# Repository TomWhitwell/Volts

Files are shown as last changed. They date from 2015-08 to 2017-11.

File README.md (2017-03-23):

##Turing Mini Voltages Expander   

This is a simple, low-parts count, low-current expander for the Turing Machine Random Sequencer in 4HP. 

It acts like a variable 5-bit digital-to-analog converter, taking 5 bits from the Turing Machine GATES expansion port, running them through five potentiometers and giving one summed voltage output.   

Multiple mini expanders can be daisychained from one Turing sequencer to give melodically different outputs that are all related to (and change with) the main Turing sequence.   

Designed in one day while on holiday in Cornwall.   

NB: the panel design in this repository is a bit strange; raw fibreglass with gold lines and no text - you might want to tweak it if you want a panel that matches the other the Turing expanders. 

BOM: 
- 5 x Vertical 50k Linear Potentiometers ([Alpha 9mm](https://www.thonk.co.uk/shop/alpha-9mm-pots/) will work well)
- 8 x 10k Resistors 
- 1 x 1k Resistor 
- 1 x TL072 Op Amp 
- 2 x 100n Ceramic Capacitors 
- 1 x [Thonkiconn Socket](https://www.thonk.co.uk/shop/thonkiconn-3-5mm-jack-sockets-x50/)  
- 2 x 16 Pin Headers 2x8 (for example 649-67997-216HLF from Mouser)
- 1 x Ribbon cable
- 5 x Knobs

This board should be built with pots that bolt to the panel, like the Alphas above. Plastic shaft pots (or the little ones with an indicator line on the shaft) will work fine, but the only support between the board and the panel will be the nut on the socket. There is a mounting hole on the PCB, so you can screw an 11m hex spacer to that, and epoxy the other end to the panel, if you want to use those pots. 

Status:  
January 2016: Updated prototype built, working well. 
September 2015: First board validated idea, contained embarrassing errors. Those fixed, second prototypes ordered.  
August 2015: Awaiting first prototypes  

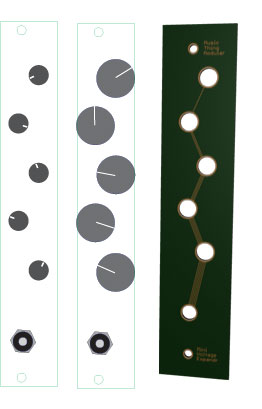
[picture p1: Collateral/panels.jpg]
First image mockups


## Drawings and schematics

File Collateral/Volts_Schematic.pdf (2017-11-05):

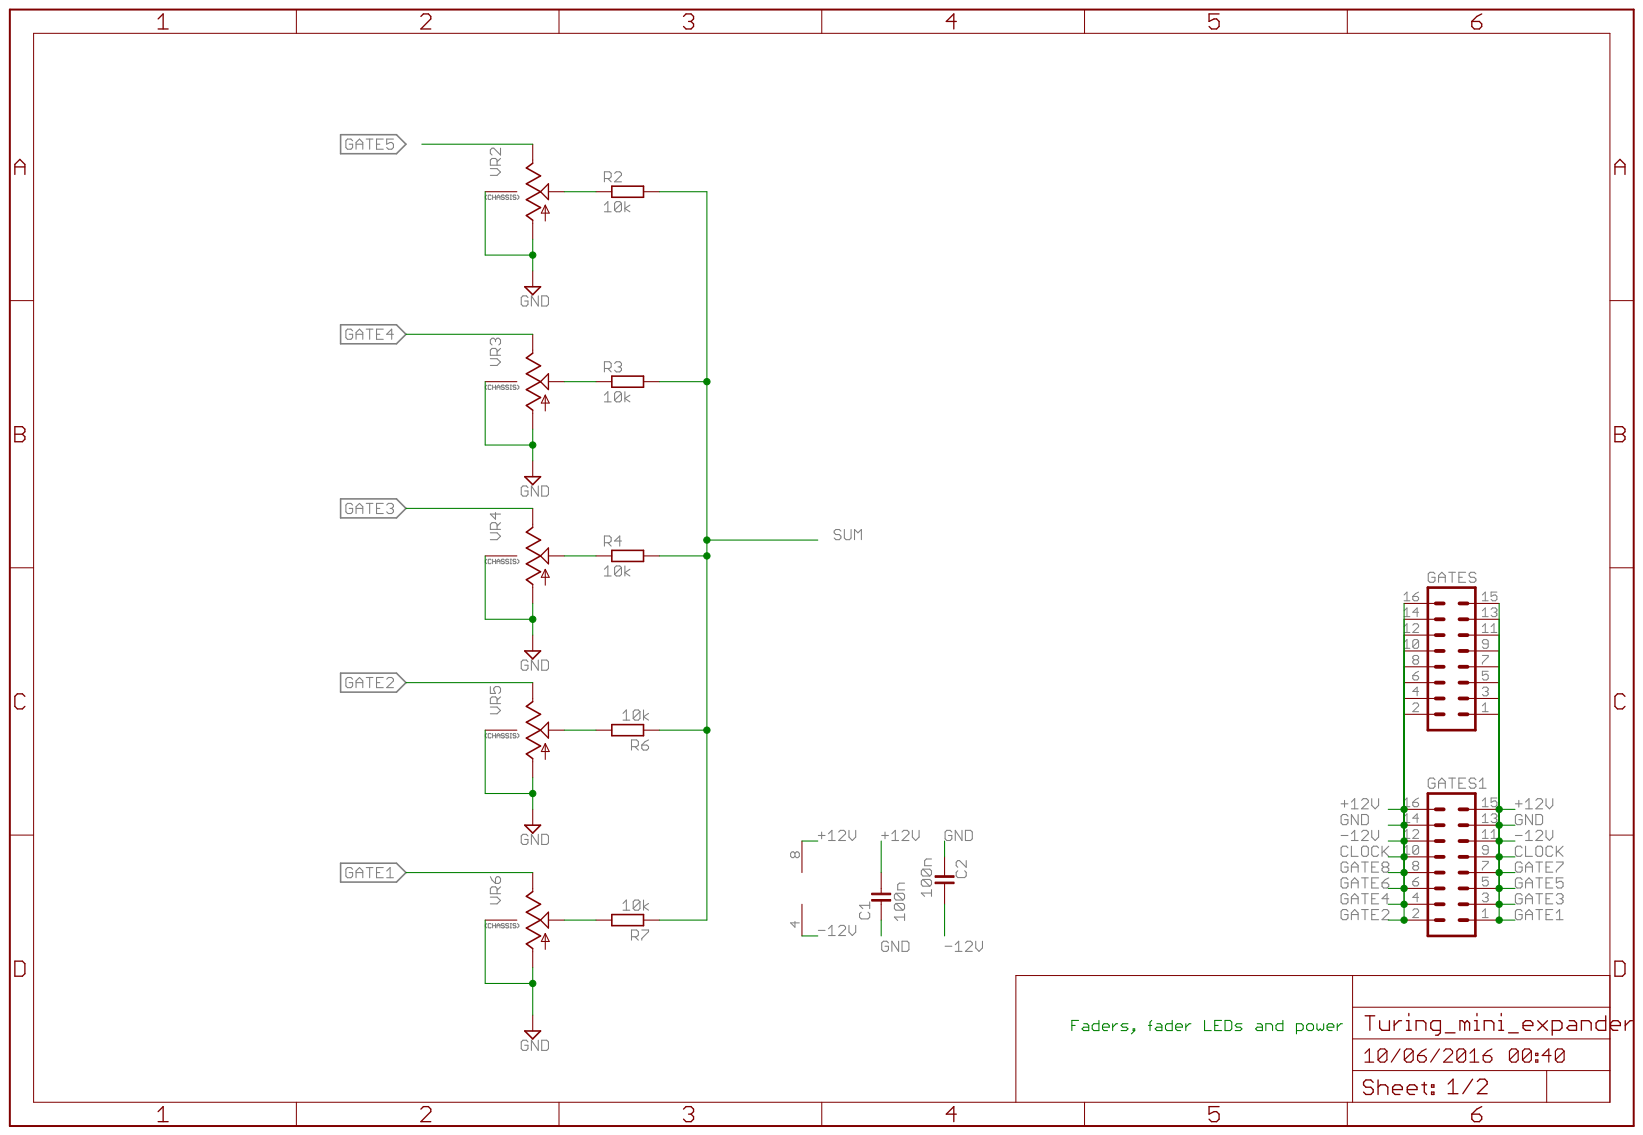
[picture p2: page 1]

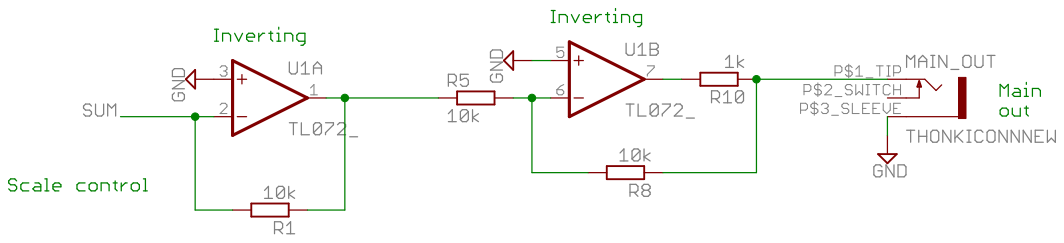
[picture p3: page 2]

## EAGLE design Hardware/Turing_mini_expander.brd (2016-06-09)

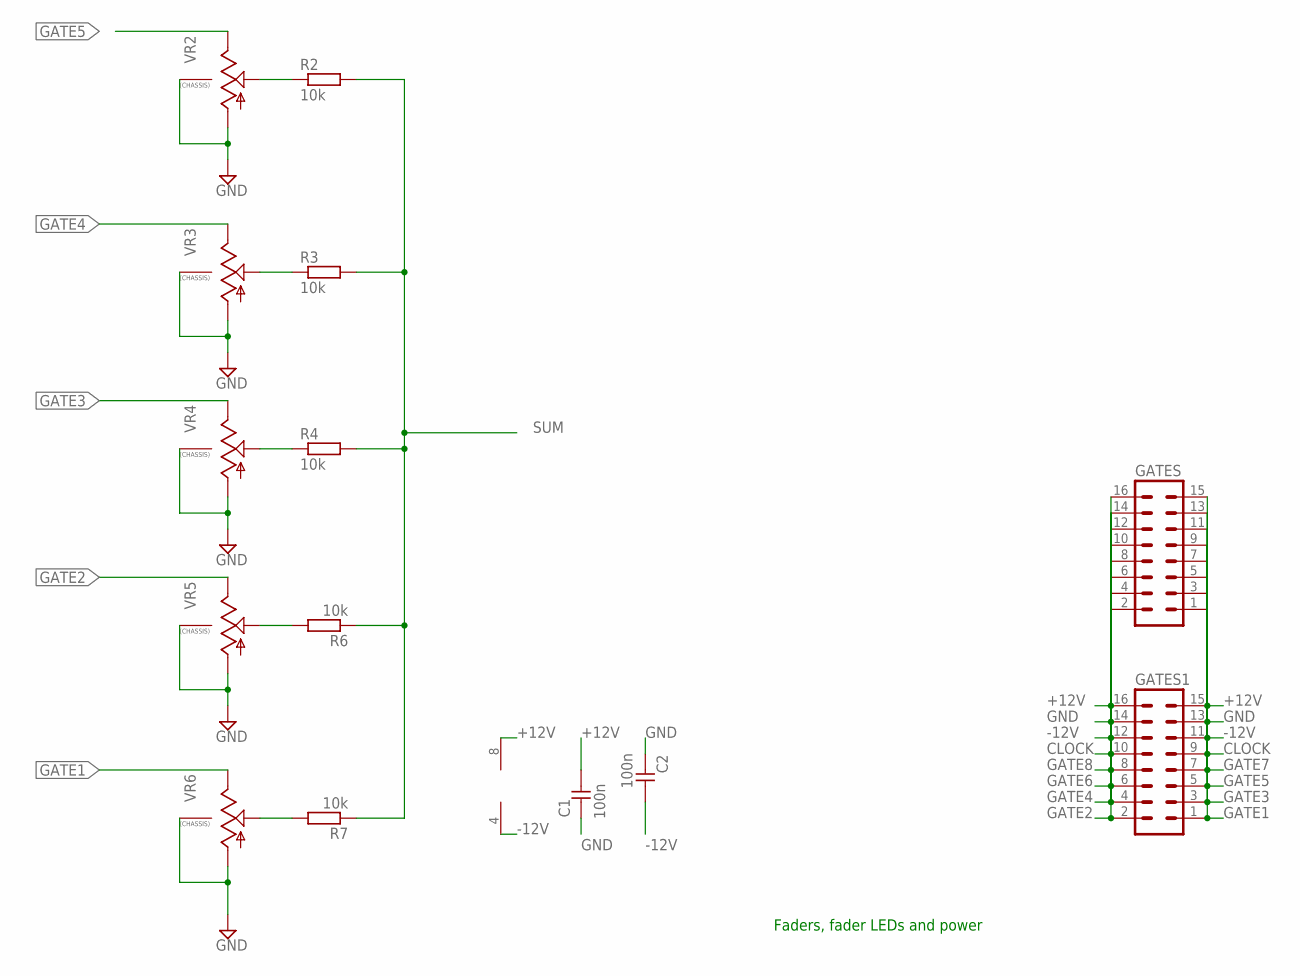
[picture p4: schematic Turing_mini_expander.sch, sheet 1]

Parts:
C1, C2: 100n; C050-024X044
GATES, GATES1: MA08-2
R2, R3, R4, R6, R7: 10k; 7MM_RESISTOR
U1: TL072_; DIL08
VR2, VR3, VR4, VR5, VR6: 9MM_SNAP-IN_POT_CHASSIS; 9MM_SNAP-IN_POT

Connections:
+12V: C1.1, GATES.15, GATES.16, GATES1.15, GATES1.16, U1.8 (V+)
-12V: C2.1, GATES.11, GATES.12, GATES1.11, GATES1.12, U1.4 (V-)
CLOCK: GATES.9, GATES.10, GATES1.9, GATES1.10
GATE1: GATES.1, GATES1.1, VR6.3 (E)
GATE2: GATES.2, GATES1.2, VR5.3 (E)
GATE3: GATES.3, GATES1.3, VR4.3 (E)
GATE4: GATES.4, GATES1.4, VR3.3 (E)
GATE5: GATES.5, GATES1.5, VR2.3 (E)
GATE6: GATES.6, GATES1.6
GATE7: GATES.7, GATES1.7
GATE8: GATES.8, GATES1.8
GND: C1.2, C2.2, GATES.13, GATES.14, GATES1.13, GATES1.14, VR2.1 (A), VR2.CHASSIS2, VR3.1 (A), VR3.CHASSIS2, VR4.1 (A), VR4.CHASSIS2, VR5.1 (A), VR5.CHASSIS2, VR6.1 (A), VR6.CHASSIS2; also elsewhere on the board
unnamed: R2.1, VR2.2 (S)
unnamed: R3.1, VR3.2 (S)
unnamed: R4.1, VR4.2 (S)
unnamed: R6.2, VR5.2 (S)
unnamed: R7.2, VR6.2 (S)
SUM: R2.2, R3.2, R4.2, R6.1, R7.1; also elsewhere on the board

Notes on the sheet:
Faders, fader LEDs and power

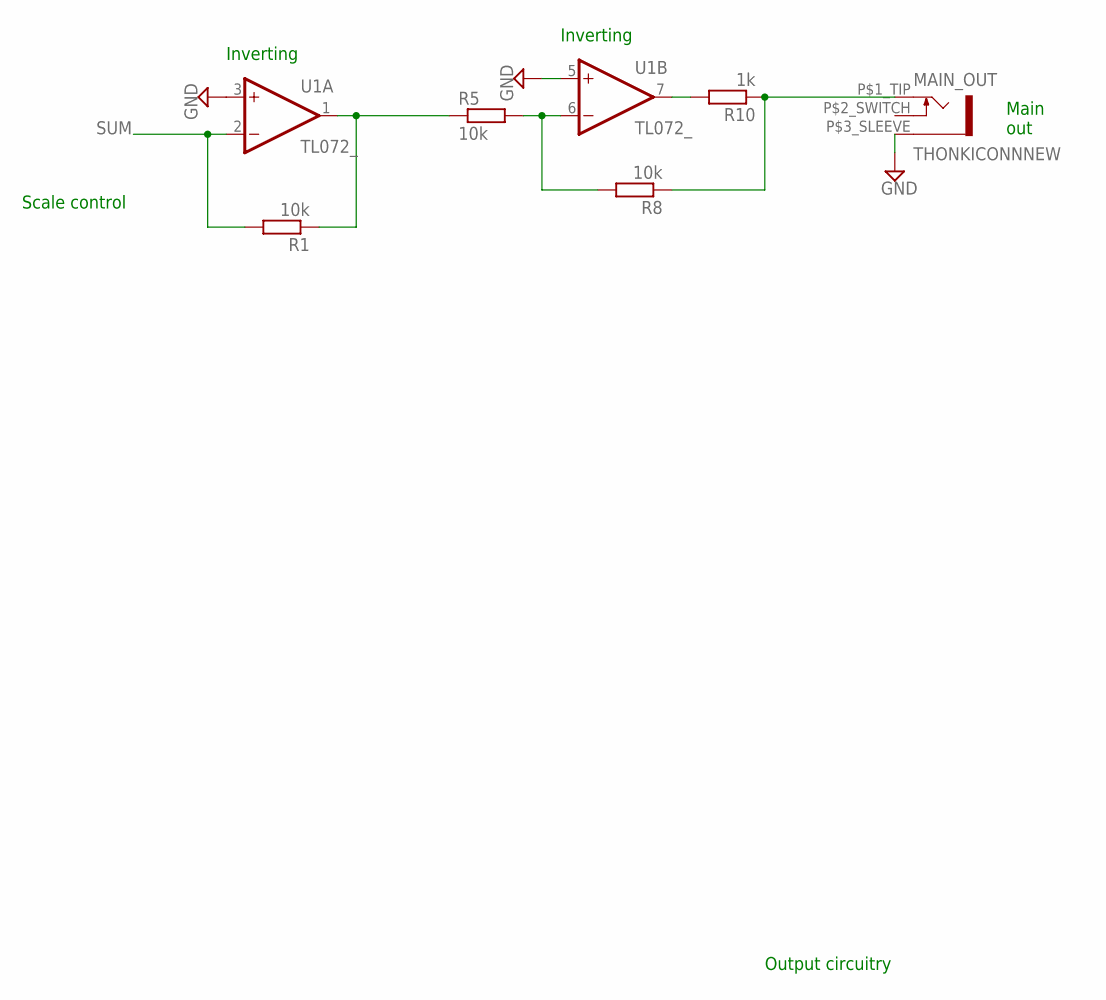
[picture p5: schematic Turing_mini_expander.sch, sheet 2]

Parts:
MAIN_OUT: THONKICONNNEW; WQP-PJ301M-12_JACK
R1, R5, R8: 10k; 7MM_RESISTOR
R10: 1k; 7MM_RESISTOR
U1: TL072_; DIL08

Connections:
GND: MAIN_OUT.P$3_SLEEVE (SLEEVE), U1.3 (+IN), U1.5 (+IN); also elsewhere on the board
unnamed: R5.2, R8.2, U1.6 (-IN)
unnamed: MAIN_OUT.P$1_TIP (TIP), R8.1, R10.1
unnamed: R10.2, U1.7 (OUT)
unnamed: R1.1, R5.1, U1.1 (OUT)
SUM: R1.2, U1.2 (-IN); also elsewhere on the board

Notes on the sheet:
Scale control
Main out
Output circuitry
Inverting

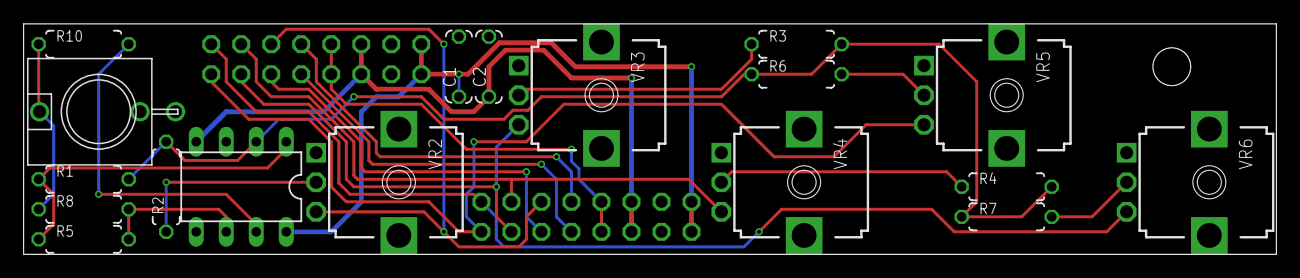
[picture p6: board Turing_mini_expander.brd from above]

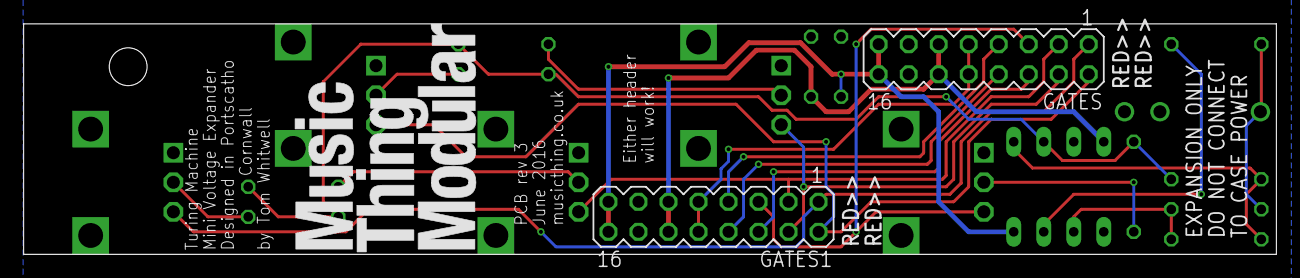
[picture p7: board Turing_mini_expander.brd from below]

Board: 4 copper layers, 106.0 x 19.5 mm, 21 parts (2 on the bottom side), 22 nets.

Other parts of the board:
U$1: MOUNTING_HOLE

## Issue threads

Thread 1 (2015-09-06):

PCB not centred vertically on panel

TomWhitwell, 2015-09-06:
PCB is
8.69mm from the top
13.8mm from the bottom

Should move 2.55mm down

so pbc becomes
11.24 from top
11.25 from bottom

Closed 2015-09-06.

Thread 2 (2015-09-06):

Need top mounting / support hole if module to be used with spindle-only pots

TomWhitwell, 2015-09-06:
There is space next to top pot for a screw + spacer

10mm hex spacer would do it - put a screw hole on the PCB, let people glue it onto the front panel - maybe a raw PCB

Closed 2015-09-06.

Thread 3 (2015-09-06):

Thonkiconn connector incorrect

TomWhitwell, 2015-09-06:
Connections wrong, redrew and routed

Closed 2015-09-06.

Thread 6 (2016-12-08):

BOM missing 100n caps

okyeron, 2016-12-08:
BOM needs to be updated with two 100n capacitors for C1 and C2

TomWhitwell, 2016-12-08:
Thanks, Done!

Closed 2016-12-08.

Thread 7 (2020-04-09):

Volts doesn't sustain voltage value

davidebellotta, 2020-04-09:
i'm running into some problems with my volts.
On every step it gives the value and then drops to 0v, so i can not control an oscillator with it, it's like it doesn't sustain the voltage out but always resets to 0

TomWhitwell, 2020-04-09:
Hi, One thing would be to check you have it connected to the GATES output, not the PULSES output.
Tom

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

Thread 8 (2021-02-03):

My volts gets super hot when in use??

Alexcoleman268, 2021-02-03:
I was testing the board out before I put the face plate on and I noticed my board gets veryyy hot and it also makes the lights dim on the Turing machine?

THanks!!

TomWhitwell, 2021-02-03:
Hi, that doesn't sound good - there's very little to a volts, so the most likely cause would be a reversed chip, possibly a reversed connector cable, or a short circuit somewhere. Check all the solder points, and if you like post high-res pictures of both sides of the board - and  the board connected to the Turing - here.

Alexcoleman268, 2021-02-03:
there's no link??

TomWhitwell, 2021-02-03:
(post the images here on this thread!)

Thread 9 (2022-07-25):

Volts outputting gates

Mowgliart, 2022-07-25:
I just completed building the volts expander for my Turing machine which is fully operational with a pulses expander.
The volts expander is outputting a series of gates with the voltage jumping from -10V to +10V.
I've double-checked all the soldering and I can't see any blatant mistakes. I've built many kits before with no issues and I built the Turing machine and pulses a while back without any issues.

Any idea of what could be wrong or how to troubleshoot?

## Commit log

2015-08-26 Initial upload
    [Turing_mini_expander.GBL, Turing_mini_expander.GBO, Turing_mini_expander.GBP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]
2015-09-06 Thonkiconn error corrected and re-routed
    [Turing_mini_expander.brd, Turing_mini_expander.sch]
2015-09-06 Fixes after first photo
    Fixes #2, fixes #3, fixes #4
    [Turing_mini_expander.brd, Turing_mini_expander.sch]
2015-09-06 Centre pcb on panel
    fixes #1
    [turingminiexpanderpanel.brd]
2015-09-12 Add vector logo to back of board
    [Turing_mini_expander.brd]
2015-09-12 vector logos on panel
    [turingminiexpanderpanel.brd]
2015-09-12 reroute fatter traces
    [Turing_mini_expander.brd, Turing_mini_expander.sch]
2015-09-12 Rev 2 Board and Panel complete and prototypes ordered
    [Turing_mini_expander.GBL, Turing_mini_expander.GBO, Turing_mini_expander.GBP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]
2015-10-19 Merge remote-tracking branch 'origin/master'
    Conflicts:
    Hardware/Eagle/Turing_mini_expander.brd
    [Turing_mini_expander.brd, Turing_mini_expander.sch]
2016-01-05 Revert "Merge remote-tracking branch 'origin/master'"
    This reverts commit c677e9c759e717a54841b66673ad6128330ede4f.
    [Turing_mini_expander.brd, Turing_mini_expander.sch]
2016-01-05 Value changes
    [Turing_mini_expander.brd, Turing_mini_expander.sch]
2016-01-24 Folder reorganisation
    [Turing_mini_expander.GBL, Turing_mini_expander.GBO, Turing_mini_expander.GBP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]
2016-06-09 Rev 3 PCB
    Reverses order of pots
    [Turing_mini_expander.brd, Turing_mini_expander.sch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]
2017-11-05 Add schematic
2017-11-05 Both pages in schematic now!
